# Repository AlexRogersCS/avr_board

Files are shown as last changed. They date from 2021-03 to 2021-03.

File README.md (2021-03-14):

# AVR Development Board

I like to explore different instruction sets during my Computer Architecture course - typically x86-64, ARMv7, ARMv8 and AVR. For the latter, I thought it would be fun to have a small cheap development board that the students could experiment with, so I designed one.

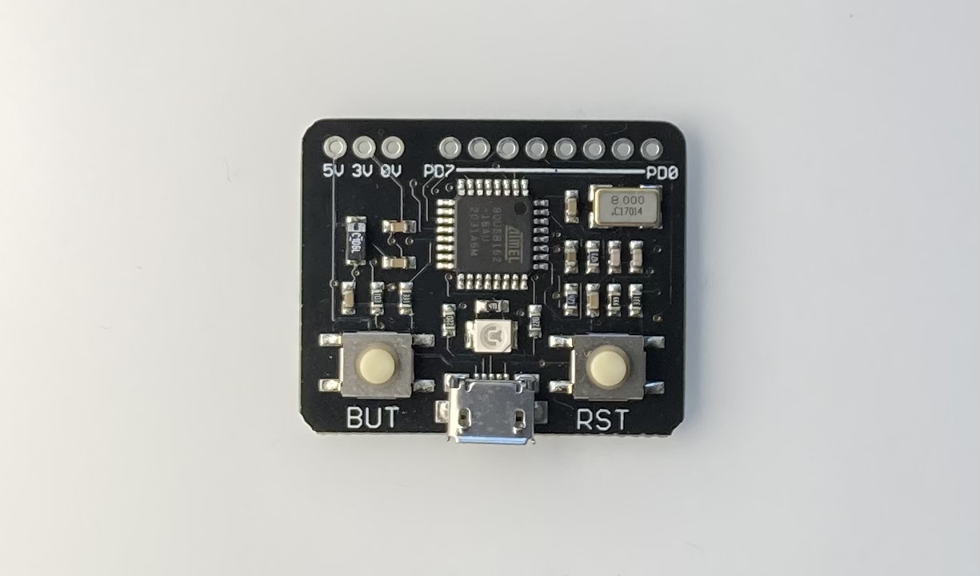
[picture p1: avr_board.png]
AVR Development Board


The board uses an 8-bit Atmel AT90USB162 processor since it requires minimal external components, comes with a factory programmed USB bootloader so no additional programmer is required, and can implement USB devices such as single key keyboards and mice.

This repository contains the Eagle CAD, Gerber and placement files, along with the BOM and a couple of simple code examples that use AVR-GCC and Gerd’s AVR assembler ([gavrasm](http://www.avr-asm-tutorial.net/gavrasm/index_en.html)).

## Development Tools

The AVR-GCC developnment tools and the programmer can be installed as below:

On Ubuntu 20.04 LTS

```
> sudo apt-get install libusb
> sudo apt-get install dfu-programmer
> sudo apt-get install gcc-avr binutils-avr avr-libc
```

On Fedora 32

```
> sudo dnf install libusb
> sudo dnf install dfu-programmer
> sudo dnf install avr-gcc avr-binutils avr-libc
```

Gerd’s AVR assembler is a simple assembler that generate hex files directly. It supports many AVR processors, including the AT90USB162, without requiring any additional configuration files. It can be installed from [here](http://www.avr-asm-tutorial.net/gavrasm/index_en.html).

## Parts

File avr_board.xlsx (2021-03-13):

No. | Description | Package | Value | Qty | RefDefs | Manufacturer | Part Number | Digikey Number | Digikey Page
1 | AT90USB162 | 32-TQFP | AT90USB162-16AU | 1 | U1 | Microchip | AT90USB162-16AU | AT90USB162-16AU-ND | https://www.digikey.co.uk/product-detail/en/microchip-technology/AT90USB162-16AU/AT90USB162-16AU-ND/1914389
2 | CAP CER 0.1UF 25V X5R 0603 | 0603 | 0.1uF | 5 | C1, C2,C5,C7,C8 | Samsung | CL10A104KA8NNNC | 1276-1857-1-ND | https://www.digikey.co.uk/product-detail/en/samsung-electro-mechanics/CL10A104KA8NNNC/1276-1857-1-ND/3889943
3 | CAP CER 20PF 50V C0G/NP0 0603 | 0603 | 20pF | 2 | C3, C4 | Walsin Technology Corporation | 0603N200J500CT | 1292-1498-1-ND | https://www.digikey.co.uk/product-detail/en/samsung-electro-mechanics/CL10C200JB8NNNC/1276-1187-1-ND/3889273
4 | CAP TANT 10UF 20% 16V 1206 | EIA3216 | 10uF | 1 | C6 | Vishay | 293D106X0016A2TE3 | 718-1956-1-ND | https://www.digikey.co.uk/product-detail/en/walsin-technology-corporation/0603N200J500CT/1292-1498-1-ND/9355502
5 | CAP CER 1UF 25V X5R 0603 | 0603 | 1uF | 1 | C9 | Samsung | CL10A105KA8NNNC | 1276-1102-1-ND | https://www.digikey.co.uk/product-detail/en/samsung-electro-mechanics/CL10A105KA8NNNC/1276-1102-1-ND/3889188
6 | RES SMD 10K OHM 5% 1/10W 0603 | 0603 | 10K | 1 | R1 | Yageo | AC0603JR-0710KL | 311-10KLECT-ND | https://www.digikey.co.uk/product-detail/en/yageo/AC0603JR-0710KL/311-10KLECT-ND/2828151
7 | RES SMD 330 OHM 5% 1/10W 0603 | 0603 | 330R | 2 | R2,R4 | Yageo | AC0603JR-07330RL | YAG3664CT-ND | https://www.digikey.co.uk/product-detail/en/yageo/AC0603JR-07330RL/YAG3664CT-ND/6006513
8 | RES SMD 33K OHM 5% 1/10W 0603 | 0603 | 33K | 1 | R3 | Yageo | AC0603JR-0733KL | YAG3665CT-ND | https://www.digikey.co.uk/product-detail/en/yageo/AC0603JR-0733KL/YAG3665CT-ND/6006514
9 | RES SMD 47K OHM 5% 1/10W 0603 | 0603 | 47K | 2 | R5,R6 | Yageo | AC0603JR-0747KL | YAG3674CT-ND | https://www.digikey.co.uk/product-detail/en/yageo/AC0603JR-0747KL/YAG3674CT-ND/6006523
10 | RES SMD 470 OHM 5% 1/10W 0603 | 0603 | 470R | 1 | R7 | Yageo | AC0603JR-07470RL | YAG3673CT-ND | https://www.digikey.co.uk/product-detail/en/yageo/AC0603JR-07470RL/YAG3673CT-ND/6006522
11 | RES SMD 22 OHM 5% 1/10W 0603 | 0603 | 22R | 2 | R8,R9 | Yageo | AC0603JR-0722RL | YAG3654CT-ND | https://www.digikey.co.uk/product-detail/en/yageo/AC0603JR-0722RL/YAG3654CT-ND/6006503
12 | Red 630nm LED Indication - Discrete 1.95V | 2-PLCC | Red | 1 | D1 | Kingbright | AA3528SURSK | 754-1537-1-ND | https://www.digikey.co.uk/product-detail/en/kingbright/AA3528SURSK/754-1537-1-ND/2440543
13 | CRYSTAL 8.0000MHZ 18PF SMD | CTS406 | 8MHz | 1 | Q1 | CTS-Frequency Controls | 406I35D08M00000 | CTX1202CT-ND | https://www.digikey.co.uk/product-detail/en/cts-frequency-controls/406I35D08M00000/CTX1202CT-ND/4308779
14 | SWITCH TACTILE SPST-NO 0.02A 15V | - | - | 2 | SW1,SW2 | Panasonic | EVQ-Q2B03W | P12932SCT-ND | https://www.digikey.co.uk/product-detail/en/panasonic-electronic-components/EVQ-Q2B03W/P12932SCT-ND/762922
15 | CONN RCPT USB2.0 MICRO B SMD R/A | - | - | 1 | J1 | Amphenol ICC | 10104110-0001LF | 609-4052-1-ND | https://www.digikey.co.uk/product-detail/en/amphenol-icc-fci/10104110-0001LF/609-4052-1-ND/2350358

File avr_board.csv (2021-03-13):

C1 | 4.45 | 12.07 | 90 | 0.1uF | 0603
C2 | 26.04 | 12.07 | 90 | 0.1uF | 0603
C3 | 27.94 | 15.88 | 90 | 20pF | 0603
C4 | 29.85 | 15.88 | 90 | 20pF | 0603
C5 | 8.89 | 15.24 | 0 | 0.1uF | 0603
C6 | 5.08 | 17.14 | 270 | 10uF | EIA3216
C7 | 24.13 | 20.32 | 90 | 0.1uF | 0603
C8 | 8.89 | 18.41 | 0 | 0.1uF | 0603
C9 | 24.13 | 15.88 | 90 | 1uF | 0603
D1 | 17.14 | 8.89 | 180 | PLCC-2
J1 | 17.14 | 3.42 | 0 | 10104110-0001LF | 10104110-0001LF
Q1 | 28.89 | 20.32 | 0 | CTS406
R1 | 6.99 | 12.07 | 90 | 10K | 0603
R2 | 9.53 | 12.07 | 90 | 330R | 0603
R3 | 27.94 | 12.07 | 90 | 33K | 0603
R4 | 29.85 | 12.07 | 90 | 330R | 0603
R5 | 26.04 | 15.88 | 90 | 47K | 0603
R6 | 24.13 | 12.07 | 90 | 47K | 0603
R7 | 17.14 | 11.43 | 0 | 470R | 0603
R8 | 13.34 | 10.16 | 90 | 22R | 0603
R9 | 20.96 | 10.16 | 90 | 22R | 0603
SW1 | 6.99 | 6.35 | 0 | EVQ-Q2B03W | EVQ-Q2B03W
SW2 | 27.30 | 6.35 | 0 | EVQ-Q2B03W | EVQ-Q2B03W
U1 | 17.14 | 17.78 | 270 | AT90USB162-16AU | 32-TQFP

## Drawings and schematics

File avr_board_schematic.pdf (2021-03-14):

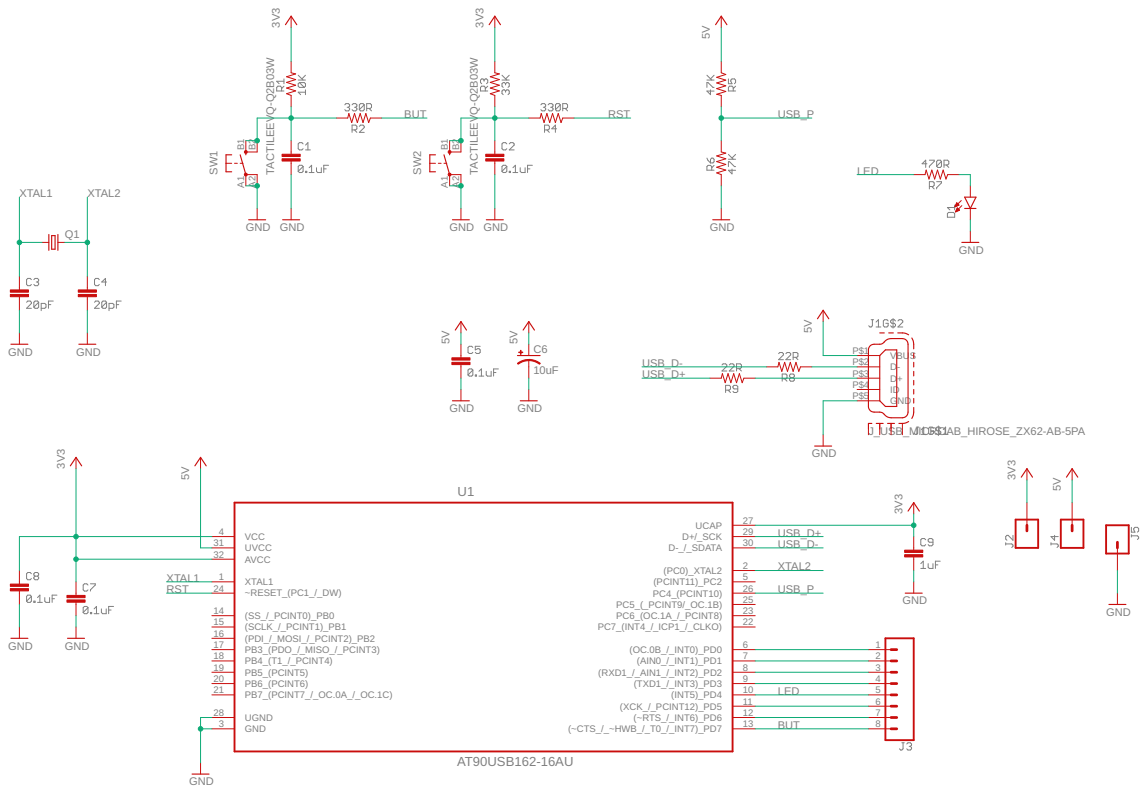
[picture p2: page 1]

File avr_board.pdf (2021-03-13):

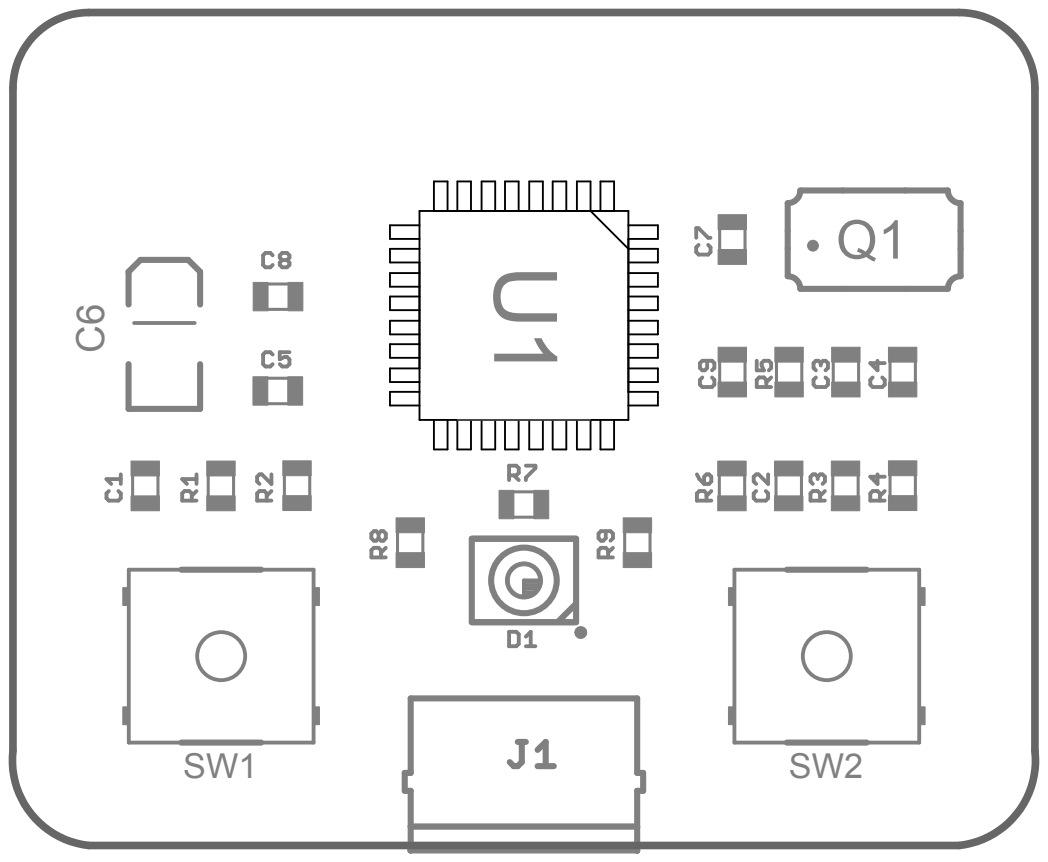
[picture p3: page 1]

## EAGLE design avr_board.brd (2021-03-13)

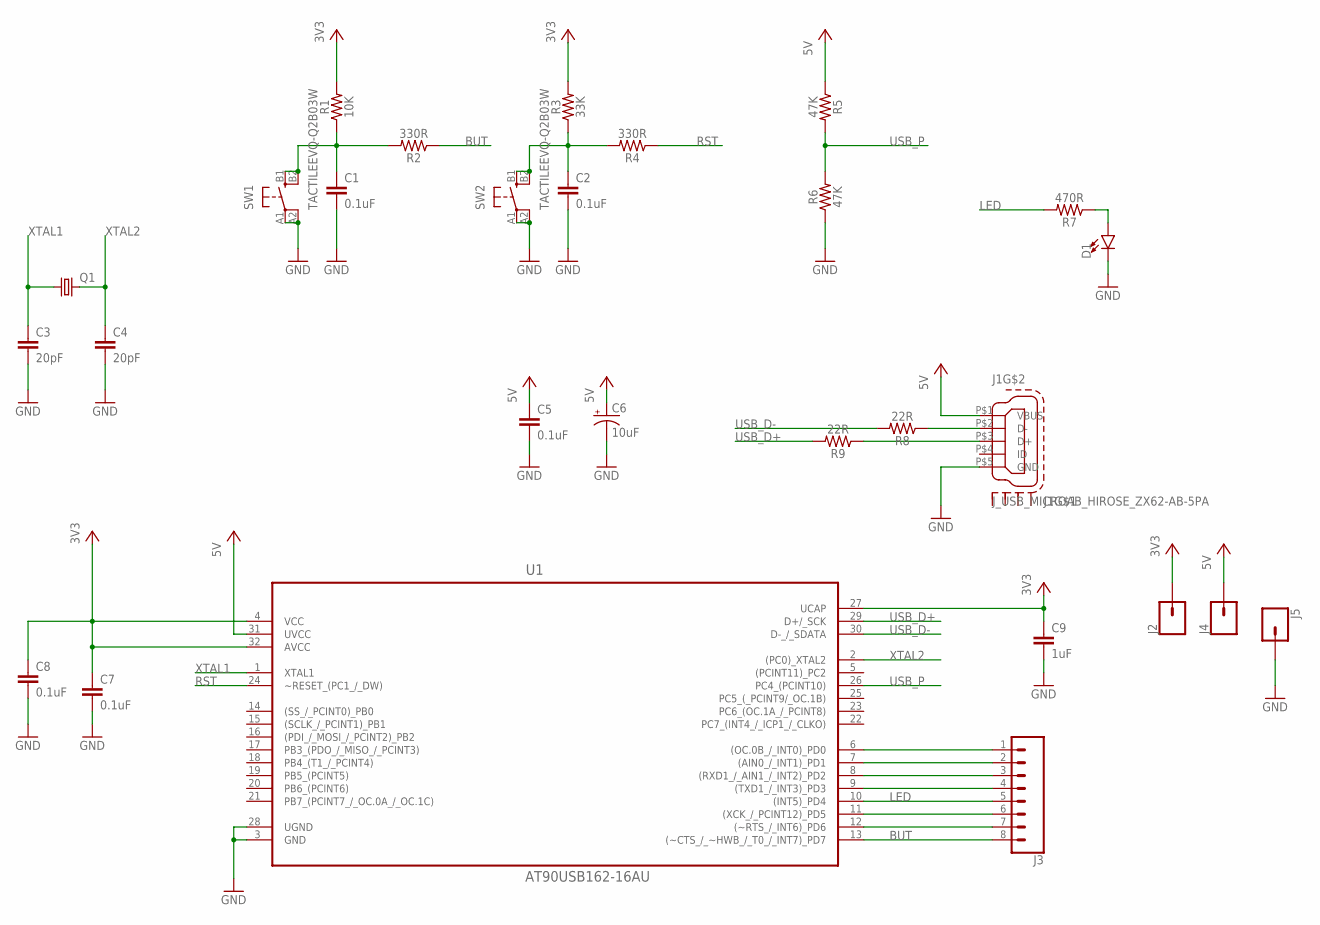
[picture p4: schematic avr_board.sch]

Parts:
C1, C2, C5, C7, C8: 0.1uF; 0603
C3, C4: 20pF; 0603
C6: 10uF; EIA3216
C9: 1uF; 0603
D1: LEDPLCC; PLCC-2
J1: J_USB_MICROAB_HIROSE_ZX62-AB-5PA
J2, J4, J5: CONN_01; 1X01
J3: CONN_08"; 1X08
Q1: CRYSTALCTS406; CTS406
R1: 10K; 0603
R2, R4: 330R; 0603
R3: 33K; 0603
R5, R6: 47K; 0603
R7: 470R; 0603
R8, R9: 22R; 0603
SW1, SW2: TACTILEEVQ-Q2B03W; TACTILE_PAC
U1: AT90USB162-16AU; QFP80P900X900X120-32N

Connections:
+5V: C5.1, C6.A (+), J1.P$1 (VBUS), J4.1, R5.1, U1.31 (UVCC)
BUT: J3.8, R2.1, U1.13 ((~CTS_/_~HWB_/_T0_/_INT7)_PD7)
GND: C1.2, C2.2, C3.2, C4.2, C5.2, C6.C (-), C7.2, C8.2, C9.2, D1.C, J1.P$5 (GND), J5.1, R6.1, SW1.A1, SW1.A2, SW2.A1, SW2.A2, U1.3 (GND), U1.28 (UGND)
LED: J3.5, R7.2, U1.10 ((INT5)_PD4)
unnamed: C1.1, R1.1, R2.2, SW1.B1, SW1.B2
unnamed: D1.A, R7.1
unnamed: C2.1, R3.1, R4.2, SW2.B1, SW2.B2
unnamed: J3.7, U1.12 ((~RTS_/_INT6)_PD6)
unnamed: J1.P$2 (D-), R8.1
unnamed: J1.P$3 (D+), R9.1
unnamed: J3.6, U1.11 ((XCK_/_PCINT12)_PD5)
unnamed: J3.4, U1.9 ((TXD1_/_INT3)_PD3)
unnamed: J3.3, U1.8 ((RXD1_/_AIN1_/_INT2)_PD2)
unnamed: J3.2, U1.7 ((AIN0_/_INT1)_PD1)
unnamed: J3.1, U1.6 ((OC.0B_/_INT0)_PD0)
RST: R4.1, U1.24 (~RESET_(PC1_/_DW))
USB_D+: R9.2, U1.29 (D+/_SCK)
USB_D-: R8.2, U1.30 (D-_/_SDATA)
USB_P: R5.2, R6.2, U1.26 (PC4_(PCINT10))
VCC: C7.1, C8.1, C9.1, J2.1, R1.2, R3.2, U1.4 (VCC), U1.27 (UCAP), U1.32 (AVCC)
XTAL1: C3.1, Q1.1, U1.1 (XTAL1)
XTAL2: C4.1, Q1.3 (2), U1.2 ((PC0)_XTAL2)

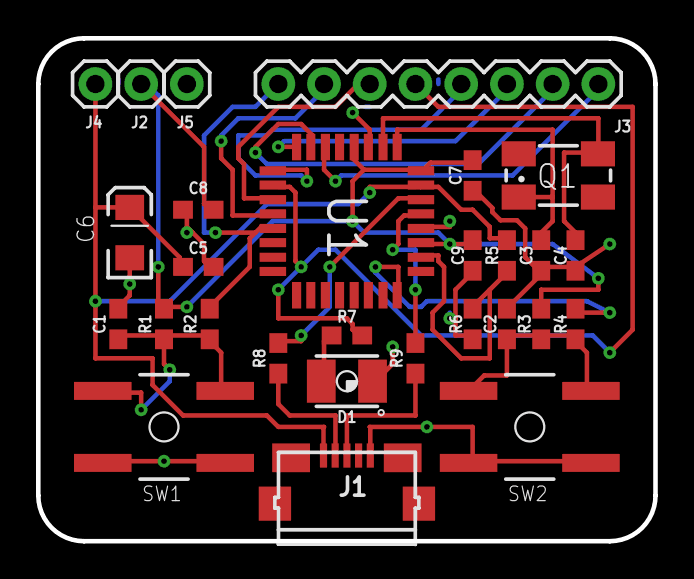
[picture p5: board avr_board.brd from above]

Board: 2 copper layers, 34.3 x 27.9 mm, 28 parts (0 on the bottom side), 22 nets.

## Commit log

2021-03-13 Initial commit.
    [avr_board.brd, avr_board.csv, avr_board.sch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]
2021-03-14 Add Gerbers.
    [copper_bottom.gbr, copper_top.gbr, drill_1_16.xln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]
2021-03-14 Add schematic.

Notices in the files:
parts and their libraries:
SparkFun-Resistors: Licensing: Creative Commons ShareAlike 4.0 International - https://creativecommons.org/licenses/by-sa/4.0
